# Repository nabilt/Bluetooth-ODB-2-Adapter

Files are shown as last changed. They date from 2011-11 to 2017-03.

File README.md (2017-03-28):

Bluetoothe OBD-II Adapter
==========================================

* Author:    Nabil Tewolde (<nabil.tewolde@gmail.com>)
* Version:   1.0.0a
* Website:   <https://nabil.me/?s=obd>
* GitHub:    <https://github.com/nabilt/Bluetooth-ODB-2-Adapter>

This hardware project is the reference schematic for the STN1110 with an added bluetooth module layed out in Eagle. Any software that is compatible with the ELM327 should be compatible with the STN1110. I use the [Torque] Android app.

[Torque]: https://market.android.com/details?id=org.prowl.torquefree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...

Tested on:

* 2000 Toyota Camry 
* 2002 Dodge Caravan

The STN1110 supports the following protocols

* SAE J1850 PWM
* SAE J1850 VPW
* SAE J1939
* ISO 9141-2
* ISO 14230-4 (KWP 2000)
* ISO 15765-4 (CAN)
* ISO 11898 (raw CAN)

Screenshots
-----------

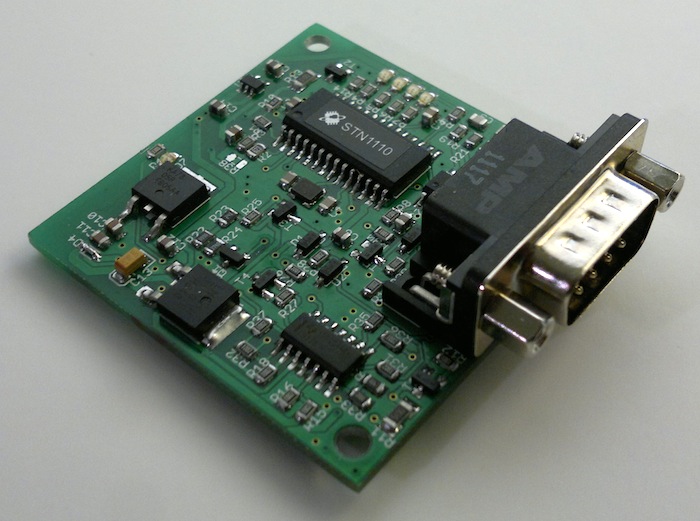
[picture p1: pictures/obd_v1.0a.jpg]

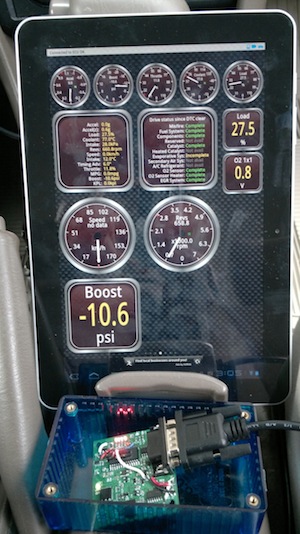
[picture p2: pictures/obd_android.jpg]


Licensing
---------

Bluetooth OBD Adapter by Nabil Tewolde is licensed under a Creative Commons Attribution-ShareAlike 3.0 Unported License.

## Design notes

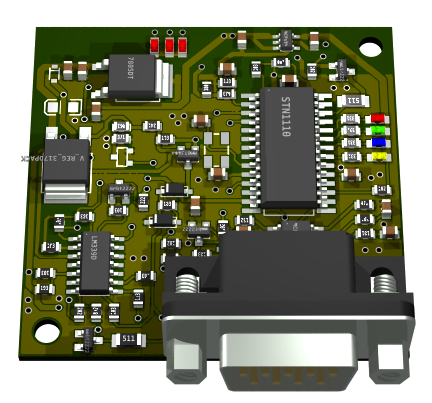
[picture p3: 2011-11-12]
pov/obd.png

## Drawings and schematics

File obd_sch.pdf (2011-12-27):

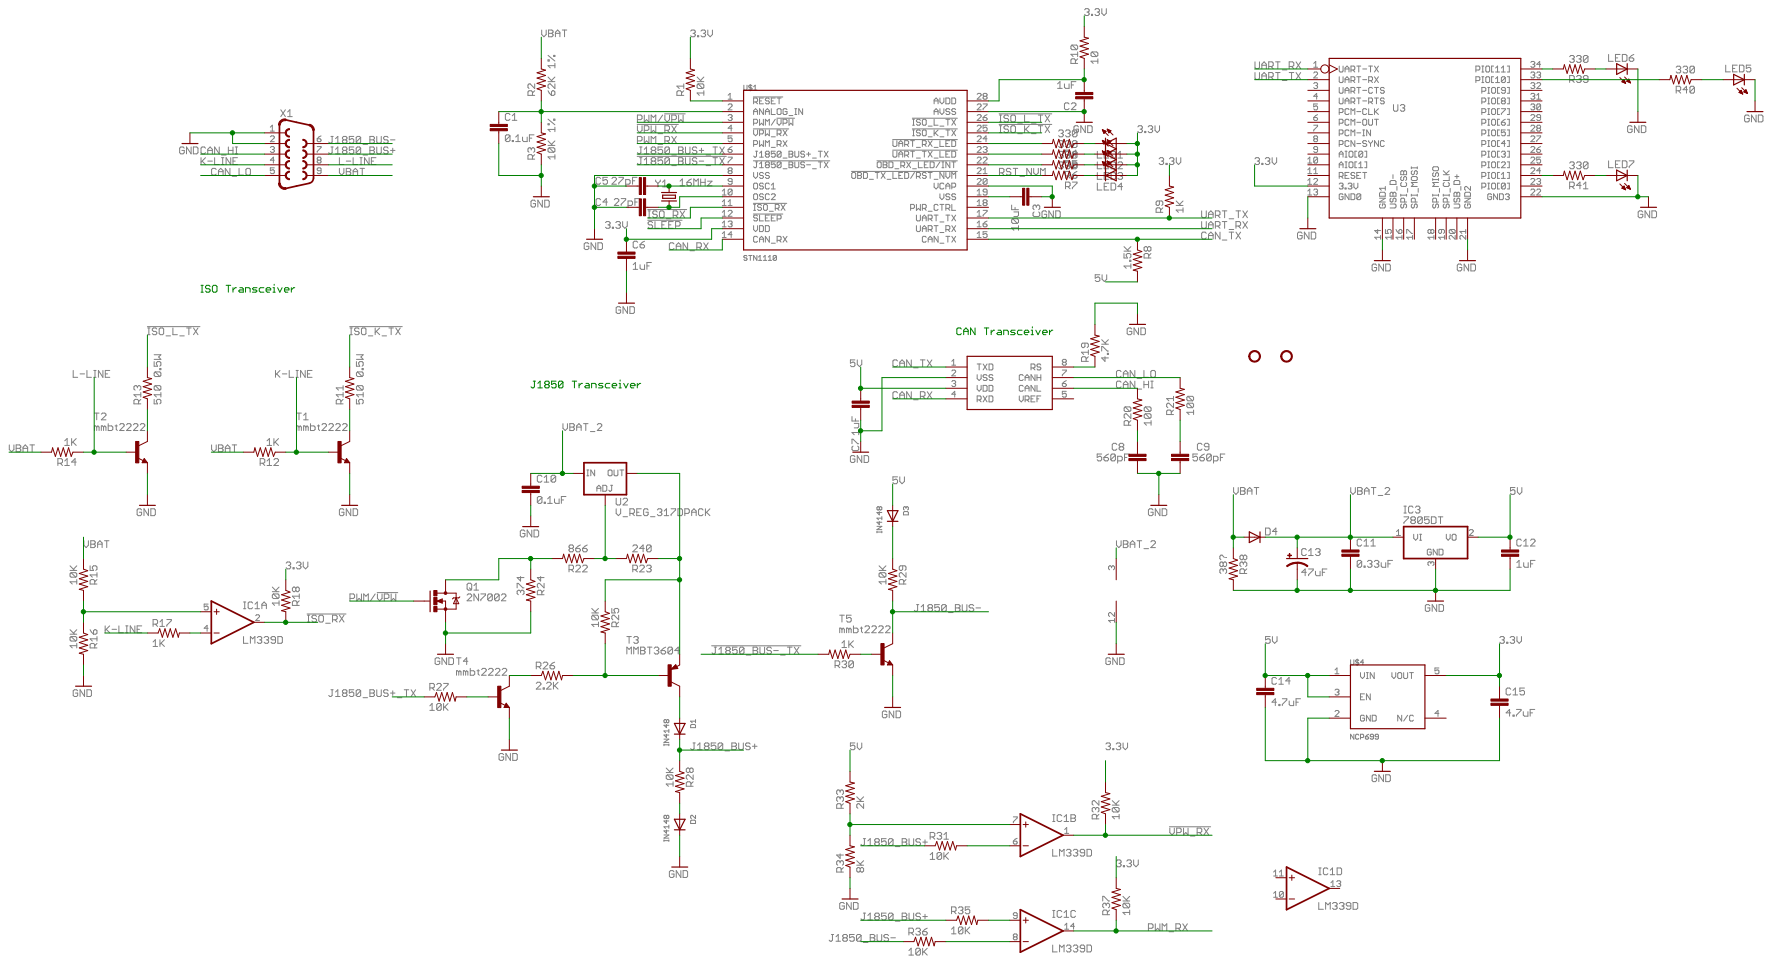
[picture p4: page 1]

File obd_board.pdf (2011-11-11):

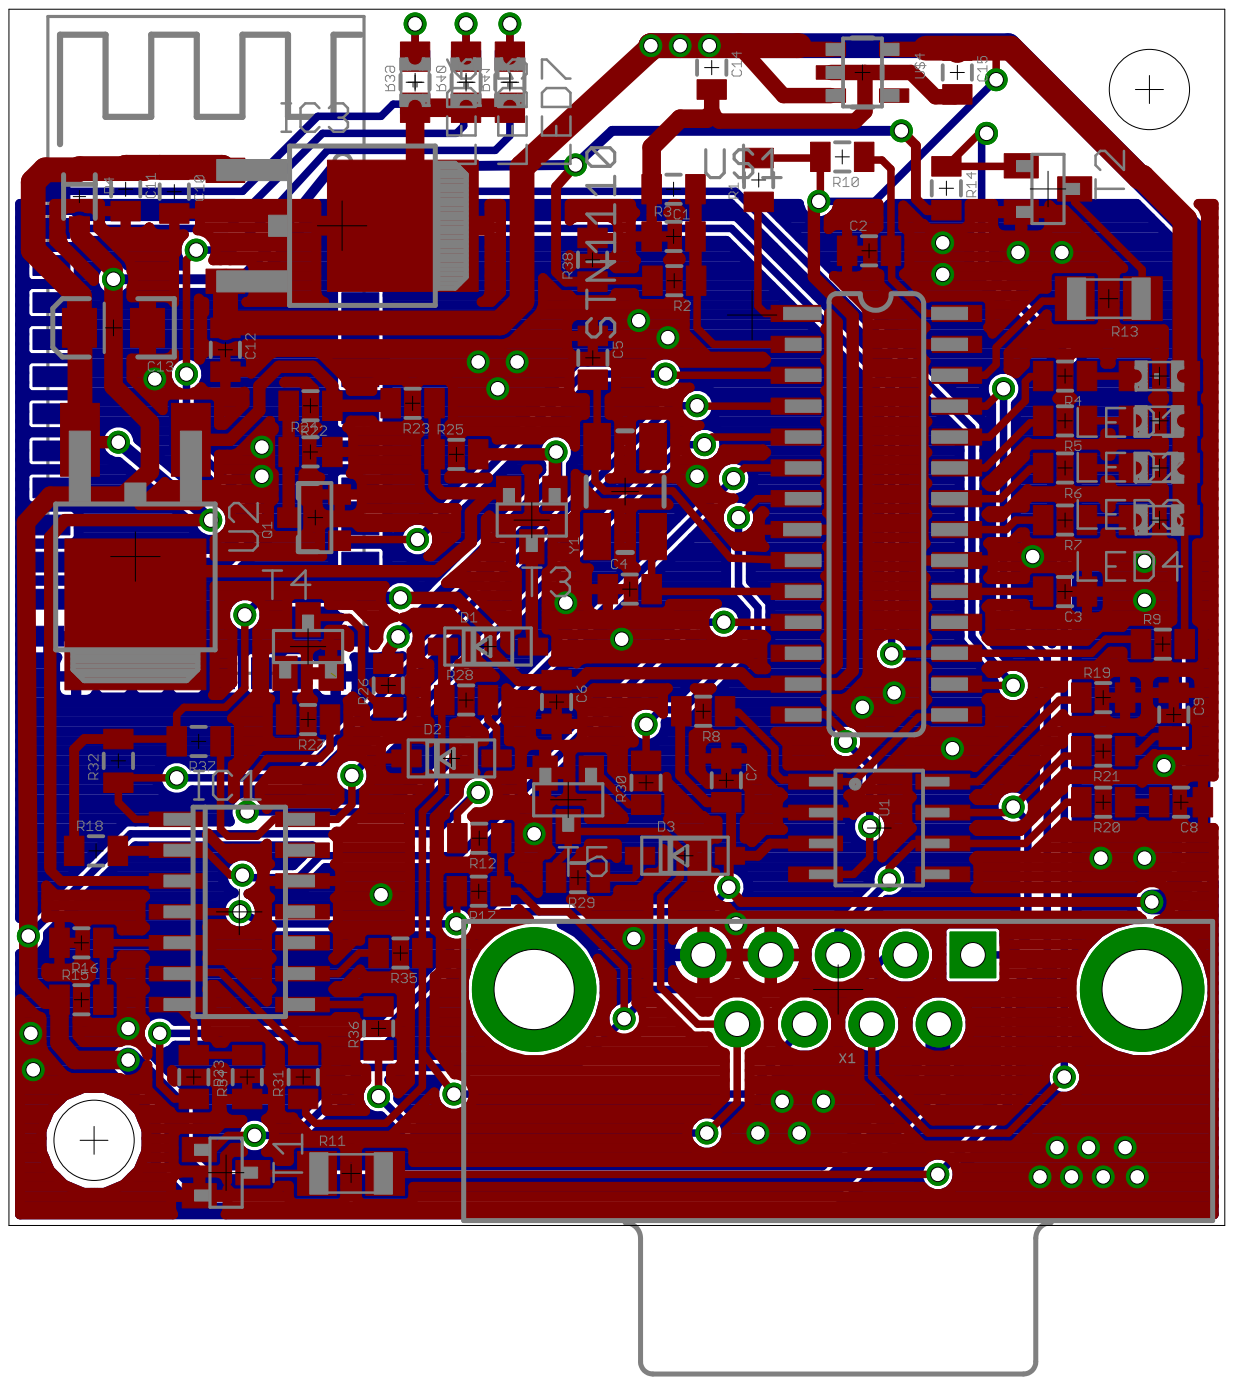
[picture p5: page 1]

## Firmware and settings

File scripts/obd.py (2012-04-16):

# You need pyserial to work for this import http://pyserial.sourceforge.net/
# easy_install pyserial
import serial

# Open bluetooth serial port
# Make sure you pair to the device first using the passcode 1234
# and change "/dev/cu.linvor-DevB" to your serial port
ser = serial.Serial("/dev/cu.linvor-DevB", baudrate=38400, timeout=1, bytesize=8, parity='N', stopbits=1)

# Request the RPM
# See http://en.wikipedia.org/wiki/OBD-II_PIDs and ELM327DS.pdf in the doc directory
ser.write('01 0C\r') 

# Read 18 bytes because the STN1110 appears to echo the command we sent
d = ser.read(18)     
print "raw data returned: ",
print list(d)

# Find the response code (41) and our RPM code (0C)
# The RPM value appears after the response code as 2 hex values
rpm = d.split("41 0C")[1].strip()
rpm = rpm.replace(" ", "")

# Divide the RPM by 4 because the car returns 4*rpm
print "RPM: ", int(rpm, 16)/4

ser.close()

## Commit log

2011-11-10 finished schematic and layout
    [obd.brd, obd.sch]
2011-11-11 added bluetooth and started routing
    [obd.brd, obd.sch]
2011-11-11 almost done routing. added obd connector
    [obd.brd, obd.sch]
2011-11-11 re-routed everything
    [obd.brd, obd.sch]
2011-11-11 finished routing again
    [obd.brd]
2011-11-11 added docs, pdf of schematic and layout
    [obd.brd, obd.sch]
2011-11-12 replaced incorrect stn1110 footprint
    [obd.brd, obd.sch]
2011-11-12 routing is done and added pov ray image
    [obd.brd]
2011-11-15 created gerber using sparkfun's sfe-gerb274x.cam
    [obd.brd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]
2011-11-15 added names part names to gerber
    [obd.brd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]
2011-11-25 add CC 3.0 licence
    [obd.brd, obd.sch]
2011-12-27 The board has been tested and found to work on a Toyota Camry. The following changes are errors that were found during testing.
    - fixed CAN HI/LOW lines
    - changed R17 resistor to 10K according to the stn1110 datasheet
    - fixed inverted vcap and vss lines on stn1110
    - fixed iso transever k/l-lines to match stn1110 datasheet
    [obd.brd, obd.sch]
2011-12-27 - fixed stn1110 foot print
    [obd.brd, obd.sch]
2011-12-27 - fixed crystal footprint
    [obd.brd, obd.sch]
2011-12-29 Version 1.0a - sent out to PCB house
    [obd.brd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]
2012-01-27 new picture and small bom change for rev 1.0a
2012-04-16 Added a sample script and more docs
